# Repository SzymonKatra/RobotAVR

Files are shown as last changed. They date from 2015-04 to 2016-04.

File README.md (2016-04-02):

# RobotAVR
Obstacle avoiding and remote controlled robot based on ATmega328P-PU. Circuit is built on prototype PCB boards.

Main parts:
* ATmega328P-PU
* HC-05 Bluetooth Module
* HC-SR04 Ultrasonic ranging module
* H-driver L293D
* 5V motors with 1:48 gear
* 65mm diameter wheels

This robot has currently two modes - remote controlling and obstacle avoiding.
Connect via bluetooth and control robot with 'w', 's', 'a', 'd' commands or 'x' to switch mode.

LFuse: F7
HFuse: D1
EFuse: 07

Fuse bit configuration included in Eclipse project.

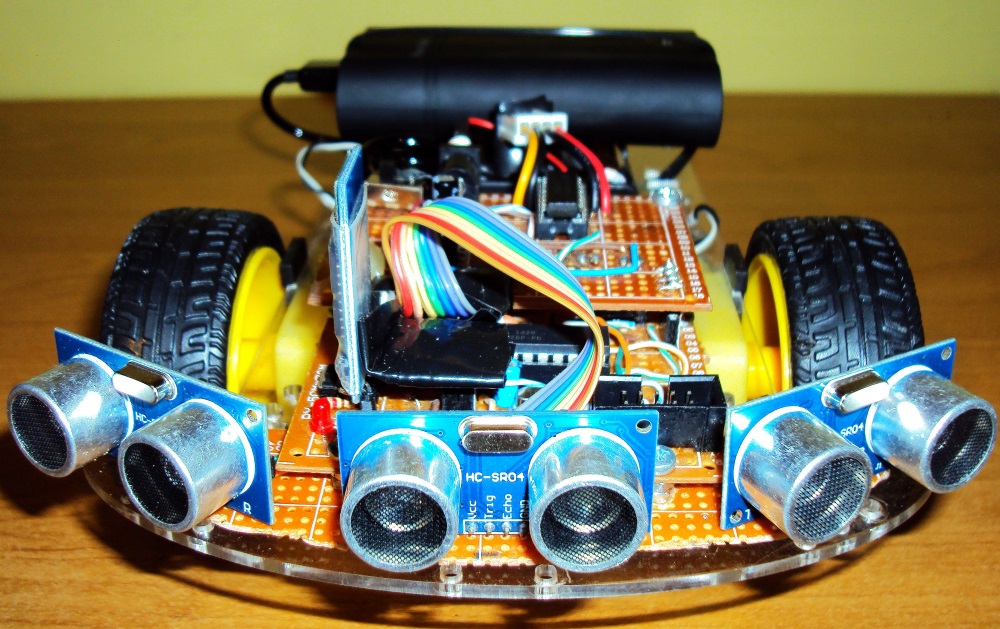
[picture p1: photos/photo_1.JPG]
RobotAVR Front Photo


Controls list and basic info:
* w - forward
* s - reverse
* a - turn left
* d - turn right
* x - change mode - bluetooth / sensor - default bluetooth
* + - speed up by 5 pulses per second (60 maximum)
* - - speed down by 5 pulses per second (10 minimum)
* m - change straight mode - left and right wheels works separately or jointly while driving straight - default separately
* c - calibrate while moving - yes / no - default no
* Default speed is 40 pulses per second
* 20 pulses equals to one complete rotation of the wheel

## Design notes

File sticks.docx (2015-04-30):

VCC F_TRIG F_ECHO GND | VCC L_TRIG L_ECHO GND | VCC R_TRIG R_ECHO GND | VCC F_TRIG F_ECHO GND | VCC L_TRIG L_ECHO GND | VCC R_TRIG R_ECHO GND | STATE(NC) RXD TXD GND VCC EN(NC) | EN(NC) VCC GND TXD RXD STATE(NC) | L_ECHO L_TRIG R_ECHO R_TRIG | R_PWM L_PWM L_DIR1 L_DIR2 | GND VCC R_DIR1 R_DIR2 | GND VCC L_COLL | GND VCC L_COLL | R_COLL VCC GND | R_COLL VCC GND | RIGHT MOTOR | LEFT MOTOR | RIGHT MOTOR | LEFT MOTOR

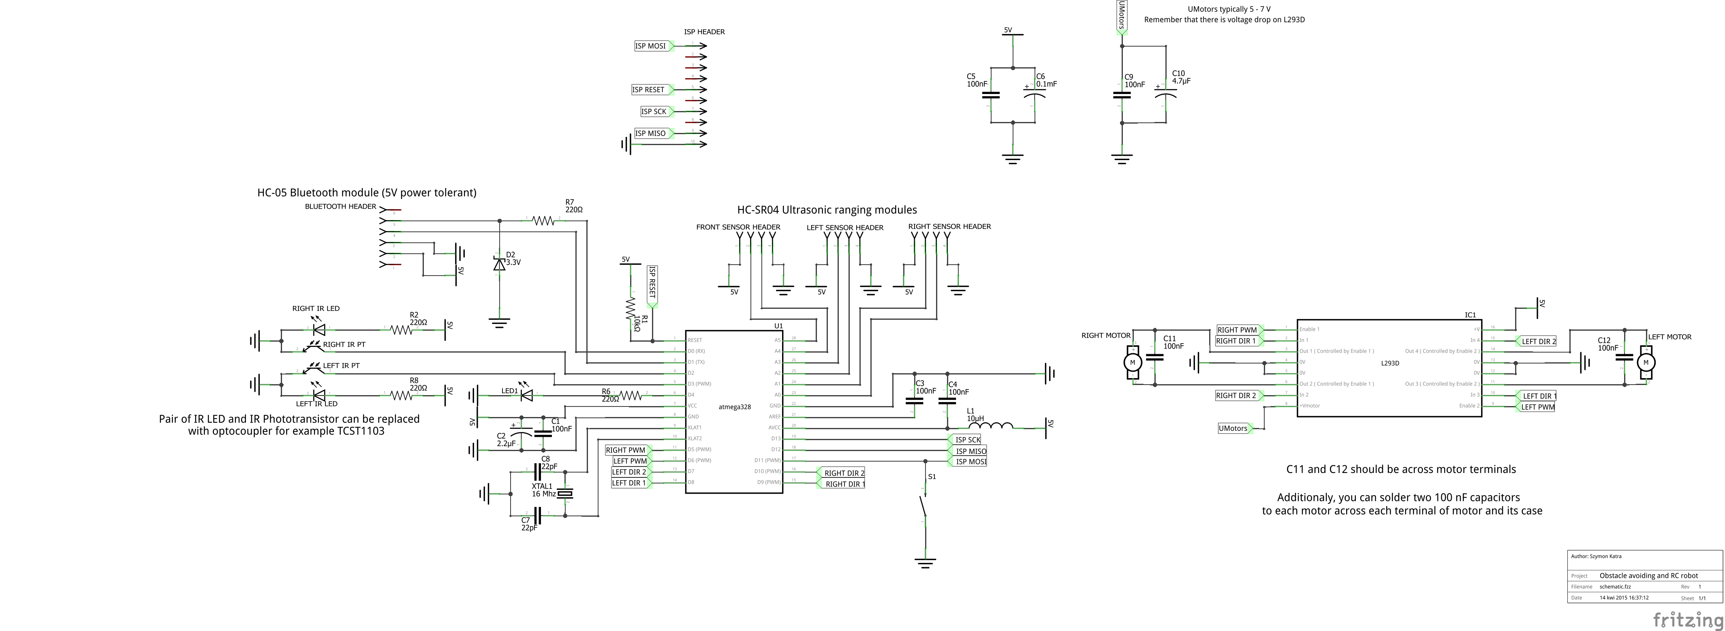
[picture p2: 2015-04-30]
schematic_schem.png

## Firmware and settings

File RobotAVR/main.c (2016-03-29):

#include <avr/io.h>
#include <util/delay.h>
#include "motors.h"
#include "wheels.h"
#include "common.h"
#include "controller.h"
#include "remote.h"
#include "sensors.h"
#include "api.h"
#include <stdio.h>
#include <util/atomic.h>

#define MIN_SPEED CONTROLLER_CALIBRATION_MIN_SPEED
#define MAX_SPEED CONTROLLER_CALIBRATION_MAX_SPEED
#define SPEED_STEP CONTROLLER_CALIBRATION_SPEED_STEP

#define PULSES_TURN 2

#define DISTANCE_LIMIT (14 * 58)
#define NEW_DISTANCE_LIMIT (17 * 58)

#define SIDE_DISTANCE_LIMIT (12 * 58)
#define SIDE_NEW_DISTANCE_LIMIT (14 * 58)

#define PRECISE_SIDE_DISTANCE_LIMIT (7 * 58)
#define PRECISE_SIDE_NEW_DISTANCE_LIMIT (7 * 58)

#define BETWEEN_WALL_DIFFERENCE (8 * 58)

//#define SIDE_SAME_TOLERANCE (3 * 58)

#define STRAIGHT_MOVE_MODE CONTROLLER_LEFT_AND_RIGHT

#define SENSORS_STEP 5
#define SENSORS_SMALL_STEP 2
#define SENSORS_90_STEP 10
#define SENSORS_180_STEP 20
#define SENSORS_MAX_SMALL_ROTATIONS 8
#define SENSORS_ENABLE_PRECISE_ROTATIONS 3

static uint8_t s_timerCounter;
static uint8_t s_started;
static volatile uint8_t s_buttonPressed;
static volatile uint8_t s_buttonLock;
static uint8_t s_speed;
static uint8_t s_straightMode;

#define CURRENT_PULSES (clamp(s_speed / 2, 5, 20))

void mainInit();

void mainBluetooth();
void mainSensors();

void mainTimerTick();

uint8_t mainCheckModeChange();
uint8_t mainCheckSpeedChange(uint8_t c);
uint8_t mainHandleButton();

int16_t abs(int16_t x)
{
	if (x < 0)
		return x * -1;
	else return x;
}
uint8_t clamp(uint8_t val, uint8_t min, uint8_t max)
{
	if (val < min) return min;
	else if (val > max) return max;

	return val;
}

int main()
{
	mainInit();

	if (buttonIsPressed()) controllerCalibrate();

	ledOn();
	s_started = 1;

	while(1)
	{
		mainBluetooth();
		mainSensors();
	}

	return 0;
}

void mainBluetooth()
{
	uint8_t cmd, lastcmd;

	cmd = lastcmd = 0;
	while(1)
	{
		if (mainHandleButton()) return;
		if (remotePoll(&cmd))
		{
			mainCheckSpeedChange(cmd);
			if (cmd == 'x')
			{
				controllerStop();
				return;
			}

			if (lastcmd == cmd && controllerIsBusy())
			{
				if (cmd == 'w' || cmd == 's')
				{
					if (s_straightMode == CONTROLLER_LEFT_AND_RIGHT_COMMON)
					{
						controllerSetCommonPulses(CURRENT_PULSES);
					}
					else
					{
						controllerSetLeftPulses(CURRENT_PULSES / 2);
						controllerSetRightPulses(CURRENT_PULSES / 2);
					}
				}
				else if (cmd == 'a' || cmd == 'd')
				{
					controllerSetLeftPulses(PULSES_TURN);
					controllerSetRightPulses(PULSES_TURN);
				}
			}
			else
			{
				controllerStop();
				switch (cmd)
				{
				case 'w':
					controllerMove(CONTROLLER_FORWARD, s_speed, CURRENT_PULSES, s_straightMode);
					break;

				case 'a':
					controllerMove(CONTROLLER_BACKWARD, s_speed, PULSES_TURN, CONTROLLER_LEFT_AND_OPPOSITE_RIGHT);
					break;

				case 's':
					controllerMove(CONTROLLER_BACKWARD, s_speed, CURRENT_PULSES, s_straightMode);
					break;

				case 'd':
					controllerMove(CONTROLLER_FORWARD, s_speed, PULSES_TURN, CONTROLLER_LEFT_AND_OPPOSITE_RIGHT);
					break;
				}
			}
			lastcmd = cmd;
		}
	}
}
void mainSensors()
{
	uint8_t s_rotations = 0;

	while(1)
	{
		/*uint8_t cmd;
		if (remotePoll(&cmd))
		{
			controllerStop();
			return;
		}*/

		controllerMove(CONTROLLER_FORWARD, s_speed, 0xFFFF, s_straightMode);
		while (sensorsGetFrontTime() > DISTANCE_LIMIT && sensorsGetLeftTime() > SIDE_DISTANCE_LIMIT && sensorsGetRightTime() > SIDE_DISTANCE_LIMIT)
		{
			s_rotations = 0;
			if(mainCheckModeChange()) return;
		}
		controllerStop();

		uint16_t sideDistanceLimit = (s_rotations >= SENSORS_ENABLE_PRECISE_ROTATIONS ? PRECISE_SIDE_DISTANCE_LIMIT : SIDE_DISTANCE_LIMIT);
		uint16_t sideNewDistanceLimit = (s_rotations >= SENSORS_ENABLE_PRECISE_ROTATIONS ? PRECISE_SIDE_NEW_DISTANCE_LIMIT : SIDE_NEW_DISTANCE_LIMIT);

		if (sensorsGetFrontTime() <= DISTANCE_LIMIT)
		{
			uint8_t goLeft = (sensorsGetLeftTime() > sensorsGetRightTime());
			while (sensorsGetFrontTime() < NEW_DISTANCE_LIMIT)
			{
				s_rotations++;
				if (goLeft)
				{
					controllerMove(CONTROLLER_BACKWARD, s_speed, SENSORS_STEP, CONTROLLER_LEFT_AND_OPPOSITE_RIGHT);
				}
				else
				{
					controllerMove(CONTROLLER_FORWARD, s_speed, SENSORS_STEP, CONTROLLER_LEFT_AND_OPPOSITE_RIGHT);
				}

				while(controllerIsBusy()) if (mainCheckModeChange()) return;
			}
		}
		else if (abs((int16_t)sensorsGetLeftTime() - (int16_t)sensorsGetRightTime()) <= BETWEEN_WALL_DIFFERENCE && sensorsGetFrontTime() > DISTANCE_LIMIT)
		{
			controllerMove(CONTROLLER_FORWARD, s_speed, 10, s_straightMode);
			while(controllerIsBusy()) if (mainCheckModeChange()) return;
		}
		else if (sensorsGetLeftTime() <= sideDistanceLimit)
		{
			s_rotations++;
			while (sensorsGetLeftTime() < sideNewDistanceLimit)
			{
				controllerMove(CONTROLLER_FORWARD, s_speed, SENSORS_SMALL_STEP, CONTROLLER_LEFT_AND_OPPOSITE_RIGHT);
				while(controllerIsBusy()) if (mainCheckModeChange()) return;
			}
		}
		else if (sensorsGetRightTime() <= sideDistanceLimit)
		{
			s_rotations++;
			while (sensorsGetRightTime() < sideNewDistanceLimit)
			{
				controllerMove(CONTROLLER_BACKWARD, s_speed, SENSORS_SMALL_STEP, CONTROLLER_LEFT_AND_OPPOSITE_RIGHT);
				while(controllerIsBusy()) if (mainCheckModeChange()) return;
			}
		}
		else
		{
			controllerMove((sensorsGetLeftTime() > sensorsGetRightTime() ? CONTROLLER_BACKWARD : CONTROLLER_FORWARD),
								       s_speed, SENSORS_180_STEP, CONTROLLER_LEFT_AND_OPPOSITE_RIGHT);
			while(controllerIsBusy()) if (mainCheckModeChange()) return;
			s_rotations = 0;
		}

		if (s_rotations >= SENSORS_MAX_SMALL_ROTATIONS)
		{
			controllerMove((sensorsGetLeftTime() > sensorsGetRightTime() ? CONTROLLER_BACKWARD : CONTROLLER_FORWARD),
					       s_speed, SENSORS_180_STEP, CONTROLLER_LEFT_AND_OPPOSITE_RIGHT);
			while(controllerIsBusy()) if (mainCheckModeChange()) return;
			s_rotations = 0;
		}
	}
}

uint8_t mainCheckModeChange()
{
	uint8_t cmd;
	uint8_t polled = remotePoll(&cmd);
	if (polled) mainCheckSpeedChange(cmd);
	if ((polled && cmd == 'x') || mainHandleButton())
	{
		controllerStop();
		return 1;
	}
	return 0;
}
uint8_t mainCheckSpeedChange(uint8_t c)
{
	uint8_t changed = 0;
	int16_t tmpSpeed = (int16_t)s_speed;
	if (c == '+')
	{
		tmpSpeed += SPEED_STEP;
		changed = 1;
	}
	else if (c == '-')
	{
		tmpSpeed -= SPEED_STEP;
		changed = 1;
	}
	else if (c == 'm')
	{
		s_straightMode = (s_straightMode == CONTROLLER_LEFT_AND_RIGHT ? CONTROLLER_LEFT_AND_RIGHT_COMMON : CONTROLLER_LEFT_AND_RIGHT);
		changed = 1;
	}
	else if (c == 'c')
	{
		uint8_t current = controllerGetCalibrateWhileMoving();
		controllerSetCalibrateWhileMoving(current == 0 ? 1 : 0);
	}

	if (tmpSpeed < MIN_SPEED) tmpSpeed = MIN_SPEED;
	else if (tmpSpeed > MAX_SPEED) tmpSpeed = MAX_SPEED;
	s_speed = (uint8_t)tmpSpeed;

	return changed;
}

uint8_t mainHandleButton()
{
	uint8_t pressed;
	ATOMIC_BLOCK(ATOMIC_FORCEON)
	{
		pressed = s_buttonPressed;
		s_buttonPressed = 0;
	}

	return pressed;
}

void mainTimerTick()
{
	if (s_started)
	{
		if (s_timerCounter++ >= 244)
		{
			s_timerCounter = 0;
			ledToggle();
		}

		if (buttonIsPressed())
		{
			if (!s_buttonLock)
			{
				s_buttonPressed = 1;
				s_buttonLock = 1;
			}
		}
		else
		{
			s_buttonPressed = 0;
			s_buttonLock = 0;
		}
	}
}

void mainInit()
{
	// not used pins as inputs with pull-ups
	DDRB &= ~(1 << PB4);
	PORTB |= (1 << PB4);
	DDRB &= ~(1 << PB5);
	PORTB |= (1 << PB5);

	s_timerCounter = 0;
	s_started = 0;
	s_buttonPressed = 0;
	s_buttonLock = 0;
	s_speed = 40;
	s_straightMode = CONTROLLER_LEFT_AND_RIGHT;

	sei();

	motorsInit();
	wheelsInit();
	controllerInitWithTimer(&mainTimerTick);
	remoteInit();
	sensorsInit();
	ledInit();
	buttonInit();
}

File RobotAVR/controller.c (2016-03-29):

#include "controller.h"

#define HANDLER_TICKS 12 // ~ 50 ms

typedef struct
{
	uint8_t enabled;
	uint16_t pulsesRemaining;
	uint16_t previousPulses;
	uint8_t pulsesPerCalibrationPeriod;
	uint8_t timerCounter;
	uint8_t calibrateCounter;
	uint8_t wheelLocked;
}controllerInternalMoveData_t;

typedef struct
{
	uint8_t leftTorque;
	uint8_t rightTorque;
}controllerCalibration_t;

#define CALIBRATION_ARRAY_SIZE ((CONTROLLER_CALIBRATION_MAX_SPEED - CONTROLLER_CALIBRATION_MIN_SPEED) / CONTROLLER_CALIBRATION_SPEED_STEP + 1)

static controllerCalibration_t s_calibration[CALIBRATION_ARRAY_SIZE];

static volatile controllerInternalMoveData_t s_common;
static volatile controllerInternalMoveData_t s_left;
static volatile controllerInternalMoveData_t s_right;

static volatile controllerCalibration_t s_calibrating;
static volatile uint8_t s_calibrationEnabled;
static volatile uint8_t s_calibrateWhileMoving;

static volatile timerTick_f s_timerTickFunction;

static void controllerResetData(volatile controllerInternalMoveData_t* data);
static void controllerFillOption(volatile controllerInternalMoveData_t* data, uint8_t speed, uint16_t pulses);

static void controllerCommonHandler();

// -1 if you don't need to do any action
// -2 if you must stop motor
// otherwis returns new torque and you must reset wheel counter
static int16_t controllerHandler(volatile controllerInternalMoveData_t* data, uint16_t pulses, uint8_t torque, volatile uint8_t* calibrating);

void controllerInit()
{
	controllerInitWithTimer(NULL);
}
void controllerInitWithTimer(timerTick_f timerTick)
{
	s_timerTickFunction = timerTick;

	controllerReset();

	eepromReadData(0, &s_calibration, sizeof(controllerCalibration_t) * CALIBRATION_ARRAY_SIZE);

	s_calibrationEnabled = 0;
	s_calibrateWhileMoving = 0;

	TCCR2B |= (1 << CS22) | (1 << CS21); // clk / 256 = 62.5 KHz
	TIMSK2 |= (1 << TOIE2); // interrupt on overflow ~ 244 interrupts per second
}

void controllerStop()
{
	ATOMIC_BLOCK(ATOMIC_FORCEON)
	{
		controllerResetData(&s_common);
		controllerResetData(&s_left);
		controllerResetData(&s_right);
	}

	motorsStopAll();
}
void controllerReset()
{
	ATOMIC_BLOCK(ATOMIC_FORCEON)
	{
		controllerResetData(&s_common);
		controllerResetData(&s_left);
		controllerResetData(&s_right);
		s_calibrationEnabled = 0;
	}
}

void controllerCalibrate()
{
	s_calibrationEnabled = 1;
	_delay_ms(2000);
	for(uint8_t speed = CONTROLLER_CALIBRATION_MIN_SPEED; speed <= CONTROLLER_CALIBRATION_MAX_SPEED; speed += CONTROLLER_CALIBRATION_SPEED_STEP)
	{
		controllerMoveStartTorque(CONTROLLER_FORWARD, speed, CONTROLLER_CALIBRATION_PULSES, CONTROLLER_LEFT_AND_RIGHT, CONTROLLER_CALIBRATION_INITIAL_TORQUE, CONTROLLER_CALIBRATION_INITIAL_TORQUE);
		while(controllerIsBusy());
		uint8_t index = (speed - CONTROLLER_CALIBRATION_MIN_SPEED) / CONTROLLER_CALIBRATION_SPEED_STEP;
		s_calibration[index] = s_calibrating;

		_delay_ms(1000);
		controllerMoveStartTorque(CONTROLLER_FORWARD, speed, 20, CONTROLLER_LEFT, CONTROLLER_CALIBRATION_INITIAL_TORQUE, CONTROLLER_CALIBRATION_INITIAL_TORQUE);
		controllerMoveStartTorque(CONTROLLER_BACKWARD, speed, 20, CONTROLLER_RIGHT, CONTROLLER_CALIBRATION_INITIAL_TORQUE, CONTROLLER_CALIBRATION_INITIAL_TORQUE);
		while(controllerIsBusy());

		_delay_ms(1000);
	}

	eepromWriteData(0, &s_calibration, sizeof(controllerCalibration_t) * CALIBRATION_ARRAY_SIZE);

	s_calibrationEnabled = 0;
}

void controllerMove(uint8_t direction, uint8_t speed, uint16_t pulses, uint8_t mode)
{
	uint8_t index = (speed - CONTROLLER_CALIBRATION_MIN_SPEED) / CONTROLLER_CALIBRATION_SPEED_STEP;

	uint16_t left = s_calibration[index].leftTorque + CONTROLLER_START_ADDITIONAL_SPEED;
	if (left > 255) left = 255;
	uint16_t right = s_calibration[index].rightTorque + CONTROLLER_START_ADDITIONAL_SPEED;
	if (right > 255) right = 255;

	controllerMoveStartTorque(direction, speed, pulses, mode, (uint8_t)left, (uint8_t)right);
}
void controllerMoveNoAdditionalStartSpeed(uint8_t direction, uint8_t speed, uint16_t pulses, uint8_t mode)
{
	uint8_t index = (speed - CONTROLLER_CALIBRATION_MIN_SPEED) / CONTROLLER_CALIBRATION_SPEED_STEP;

		uint16_t left = s_calibration[index].leftTorque;
		if (left > 255) left = 255;
		uint16_t right = s_calibration[index].rightTorque;
		if (right > 255) right = 255;

		controllerMoveStartTorque(direction, speed, pulses, mode, (uint8_t)left, (uint8_t)right);
}
void controllerMoveStartTorque(uint8_t direction, uint8_t speed, uint16_t pulses, uint8_t mode, uint8_t leftStartTorque, uint8_t rightStartTorque)
{
	ATOMIC_BLOCK(ATOMIC_FORCEON)
	{
		if (mode == CONTROLLER_LEFT_AND_RIGHT_COMMON)
		{
			controllerFillOption(&s_common, speed, pulses);
			wheelsResetCounters();
			motorsSetAllSameDirection(direction, leftStartTorque, rightStartTorque);
		}
		else if (mode == CONTROLLER_LEFT_AND_OPPOSITE_RIGHT_COMMON)
		{
			controllerFillOption(&s_common, speed, pulses);
			wheelsResetCounters();
			motorsSetAllOppositeDirection(direction, leftStartTorque, rightStartTorque);
		}
		else if (mode == CONTROLLER_LEFT_AND_RIGHT)
		{
			controllerFillOption(&s_left, speed, pulses);
			controllerFillOption(&s_right, speed, pulses);
			wheelsResetCounters();
			motorsSetLeft(direction, leftStartTorque);
			motorsSetRight(direction, rightStartTorque);
		}
		else if (mode == CONTROLLER_LEFT_AND_OPPOSITE_RIGHT)
		{
			controllerFillOption(&s_left, speed, pulses);
			controllerFillOption(&s_right, speed, pulses);
			wheelsResetCounters();
			motorsSetLeft(direction, leftStartTorque);
			motorsSetRight(CONTROLLER_OPPOSITE(direction), rightStartTorque);
		}
		else if (mode == CONTROLLER_LEFT)
		{
			controllerFillOption(&s_left, speed, pulses);
			wheelsResetLeftCounter();
			motorsSetLeft(direction, leftStartTorque);
		}
		else if (mode == CONTROLLER_RIGHT)
		{
			controllerFillOption(&s_right, speed, pulses);
			wheelsResetRightCounter();
			motorsSetRight(direction, rightStartTorque);
		}
	}
}

void controllerSetLeftPulses(uint16_t pulses)
{
	ATOMIC_BLOCK(ATOMIC_FORCEON)
	{
		s_left.pulsesRemaining = pulses;
	}
}
void controllerSetRightPulses(uint16_t pulses)
{
	ATOMIC_BLOCK(ATOMIC_FORCEON)
	{
		s_right.pulsesRemaining = pulses;
	}
}
void controllerSetCommonPulses(uint16_t pulses)
{
	ATOMIC_BLOCK(ATOMIC_FORCEON)
	{
		s_common.pulsesRemaining = pulses;
	}
}

uint8_t controllerIsBusy()
{
	uint8_t tmp;
	ATOMIC_BLOCK(ATOMIC_FORCEON)
	{
		tmp = (s_common.enabled == 1 || s_left.enabled == 1 || s_right.enabled == 1);
	}
	return tmp;
}

void controllerSetCalibrateWhileMoving(uint8_t state)
{
	s_calibrateWhileMoving = state;
}
uint8_t controllerGetCalibrateWhileMoving()
{
	return s_calibrateWhileMoving;
}

static void controllerResetData(volatile controllerInternalMoveData_t* data)
{
	data->enabled = 0;
	data->pulsesRemaining = 0;
	data->previousPulses = 0;
	data->pulsesPerCalibrationPeriod = 0;
	data->timerCounter = 0;
	data->calibrateCounter = 0;
	data->wheelLocked = 0;
}
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

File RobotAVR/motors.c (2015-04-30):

#include "motors.h"

#define LEFT_PWM_DDR DDRD
#define LEFT_PWM_BIT PD6

#define RIGHT_PWM_DDR DDRD
#define RIGHT_PWM_BIT PD5

#define LEFT_DIR1_DDR DDRB
#define LEFT_DIR1_PORT PORTB
#define LEFT_DIR1_BIT PB0

#define LEFT_DIR2_DDR DDRD
#define LEFT_DIR2_PORT PORTD
#define LEFT_DIR2_BIT PD7

#define RIGHT_DIR1_DDR DDRB
#define RIGHT_DIR1_PORT PORTB
#define RIGHT_DIR1_BIT PB1

#define RIGHT_DIR2_DDR DDRB
#define RIGHT_DIR2_PORT PORTB
#define RIGHT_DIR2_BIT PB2

void motorsInit()
{
	LEFT_PWM_DDR |= (1 << LEFT_PWM_BIT);
	RIGHT_PWM_DDR |= (1 << RIGHT_PWM_BIT);

	LEFT_DIR1_DDR |= (1 << LEFT_DIR1_BIT);
	LEFT_DIR2_DDR |= (1 << LEFT_DIR2_BIT);

	RIGHT_DIR1_DDR |= (1 << RIGHT_DIR1_BIT);
	RIGHT_DIR2_DDR |= (1 << RIGHT_DIR2_BIT);

	OCR0A = 0;
	OCR0B = 0;
	TCCR0A |= (1 << COM0A1) | (1 << COM0B1) | (1 << WGM01) | (1 << WGM00); // non-inverted, fast pwm
	TCCR0B |= (1 << CS02) | (1 << CS00); // clk / 1024 = 15.625 KHz
}

void motorsSetLeftTorque(uint8_t torque)
{
	OCR0A = torque;
}
void motorsSetLeftDirection(uint8_t direction)
{
	if (direction == MOTORS_FORWARD)
	{
		LEFT_DIR1_PORT &= ~(1 << LEFT_DIR1_BIT);
		LEFT_DIR2_PORT |= (1 << LEFT_DIR2_BIT);
	}
	else // MOTORS_BACKWARD
	{
		LEFT_DIR2_PORT &= ~(1 << LEFT_DIR2_BIT);
		LEFT_DIR1_PORT |= (1 << LEFT_DIR1_BIT);
	}
}
void motorsSetLeft(uint8_t direction, uint8_t torque)
{
	if (direction == MOTORS_FORWARD)
	{
		LEFT_DIR1_PORT &= ~(1 << LEFT_DIR1_BIT);
		OCR0A = torque;
		LEFT_DIR2_PORT |= (1 << LEFT_DIR2_BIT);
	}
	else // MOTORS_BACKWARD
	{
		LEFT_DIR2_PORT &= ~(1 << LEFT_DIR2_BIT);
		OCR0A = torque;
		LEFT_DIR1_PORT |= (1 << LEFT_DIR1_BIT);
	}
}
uint8_t motorsGetLeftTorque()
{
	return OCR0A;
}
uint8_t motorsGetLeftDirection()
{
	return (LEFT_DIR2_PORT & (1 << LEFT_DIR2_BIT)) ? MOTORS_FORWARD : MOTORS_BACKWARD;
}
void motorsStopLeft()
{
	LEFT_DIR1_PORT |= (1 << LEFT_DIR1_BIT);
	LEFT_DIR2_PORT |= (1 << LEFT_DIR2_BIT);
	OCR0A = 0;
}

void motorsSetRightTorque(uint8_t torque)
{
	OCR0B = torque;
}
void motorsSetRightDirection(uint8_t direction)
{
	if (direction == MOTORS_FORWARD)
	{
		RIGHT_DIR1_PORT &= ~(1 << RIGHT_DIR1_BIT);
		RIGHT_DIR2_PORT |= (1 << RIGHT_DIR2_BIT);
	}
	else // MOTORS_BACKWARD
	{
		RIGHT_DIR2_PORT &= ~(1 << RIGHT_DIR2_BIT);
		RIGHT_DIR1_PORT |= (1 << RIGHT_DIR1_BIT);
	}
}
void motorsSetRight(uint8_t direction, uint8_t torque)
{
	if (direction == MOTORS_FORWARD)
	{
		RIGHT_DIR1_PORT &= ~(1 << RIGHT_DIR1_BIT);
		OCR0B = torque;
		RIGHT_DIR2_PORT |= (1 << RIGHT_DIR2_BIT);
	}
	else // MOTORS_BACKWARD
	{
		RIGHT_DIR2_PORT &= ~(1 << RIGHT_DIR2_BIT);
		OCR0B = torque;
		RIGHT_DIR1_PORT |= (1 << RIGHT_DIR1_BIT);
	}
}
uint8_t motorsGetRightTorque()
{
	return OCR0B;
}
uint8_t motorsGetRightDirection()
{
	return (RIGHT_DIR2_PORT & (1 << RIGHT_DIR2_BIT)) ? MOTORS_FORWARD : MOTORS_BACKWARD;
}
void motorsStopRight()
{
	RIGHT_DIR1_PORT |= (1 << RIGHT_DIR1_BIT);
	RIGHT_DIR2_PORT |= (1 << RIGHT_DIR2_BIT);
	OCR0B = 0;
}

void motorsStopAll()
{
	OCR0A = 0;
	OCR0B = 0;
	LEFT_DIR1_PORT |= (1 << LEFT_DIR1_BIT);
	LEFT_DIR2_PORT |= (1 << LEFT_DIR2_BIT);
	RIGHT_DIR1_PORT |= (1 << RIGHT_DIR1_BIT);
	RIGHT_DIR2_PORT |= (1 << RIGHT_DIR2_BIT);
}

void motorsSetAllSameDirection(uint8_t direction, uint8_t leftTorque, uint8_t rightTorque)
{
	if (direction == MOTORS_FORWARD)
	{
		LEFT_DIR1_PORT &= ~(1 << LEFT_DIR1_BIT);
		RIGHT_DIR1_PORT &= ~(1 << RIGHT_DIR1_BIT);
		OCR0A = leftTorque;
		OCR0B = rightTorque;
		LEFT_DIR2_PORT |= (1 << LEFT_DIR2_BIT);
		RIGHT_DIR2_PORT |= (1 << RIGHT_DIR2_BIT);
	}
	else // MOTORS_BACKWARD
	{
		LEFT_DIR2_PORT &= ~(1 << LEFT_DIR2_BIT);
		RIGHT_DIR2_PORT &= ~(1 << RIGHT_DIR2_BIT);
		OCR0A = leftTorque;
		OCR0B = rightTorque;
		LEFT_DIR1_PORT |= (1 << LEFT_DIR1_BIT);
		RIGHT_DIR1_PORT |= (1 << RIGHT_DIR1_BIT);
	}
}
void motorsSetAllOppositeDirection(uint8_t direction, uint8_t leftTorque, uint8_t rightTorque)
{
	if (direction == MOTORS_FORWARD)
	{
		LEFT_DIR1_PORT &= ~(1 << LEFT_DIR1_BIT);
		RIGHT_DIR2_PORT &= ~(1 << RIGHT_DIR2_BIT);
		OCR0A = leftTorque;
		OCR0B = rightTorque;
		LEFT_DIR2_PORT |= (1 << LEFT_DIR2_BIT);
		RIGHT_DIR1_PORT |= (1 << RIGHT_DIR1_BIT);
	}
	else // MOTORS_BACKWARD
	{
		LEFT_DIR2_PORT &= ~(1 << LEFT_DIR2_BIT);
		RIGHT_DIR1_PORT &= ~(1 << RIGHT_DIR1_BIT);
		OCR0A = leftTorque;
		OCR0B = rightTorque;
		LEFT_DIR1_PORT |= (1 << LEFT_DIR1_BIT);
		RIGHT_DIR2_PORT |= (1 << RIGHT_DIR2_BIT);
	}
}

void motorsSetAllTorque(uint8_t left, uint8_t right)
{
	OCR0A = left;
	OCR0B = right;
}
void motorsGetAllTorque(uint8_t* left, uint8_t* right)
{
	*left = OCR0A;
	*right = OCR0B;
}
